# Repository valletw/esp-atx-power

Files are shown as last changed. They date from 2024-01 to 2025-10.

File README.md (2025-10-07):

# ESP32 ATX Power Controller

The purpose of this project is to control a computer remotely by connecting
directly to the ATX motherboard power IO control. The control will be done with
Home Assistant by using [ESPHome](https://esphome.io) firmware.

Custom software could be written by using ESP-IDF SDK but it is not the purpose
of this project.

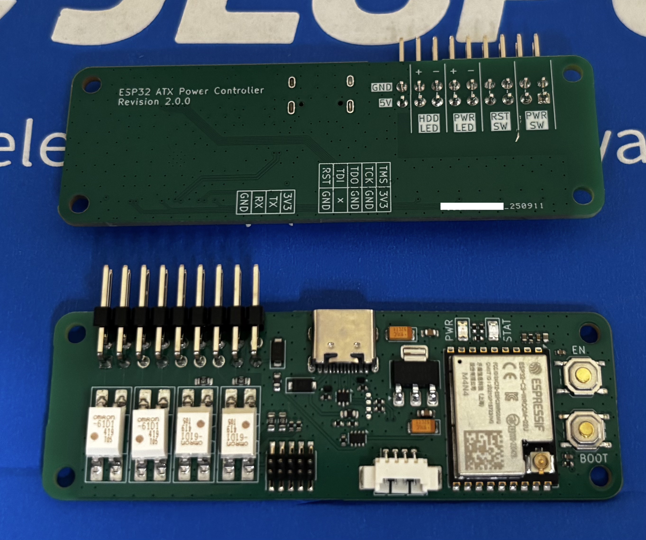
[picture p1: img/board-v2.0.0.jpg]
Board


## Hardware

Double 2.54mm pin headers are set for each ATX functionalities to manage:

- `PWR SW`: ATX power button
- `RST SW`: ATX reset button
- `PWR LED`: ATX power state LED
- `HDD LED`: ATX HDD activity LED

Two status LED are available:

- `PWR`: 3.3V state
- `STAT`: System status controlled by software

Two buttons are available for ESP32 boot sequence:

- `BOOT`: Control processor download mode on boot
- `EN`: Control processor reset

For advanced debug, the following connectors are available:

- 2x5 1.27mm pins header JTAG/SWD for external probe
- 4-pins Molex connector for UART

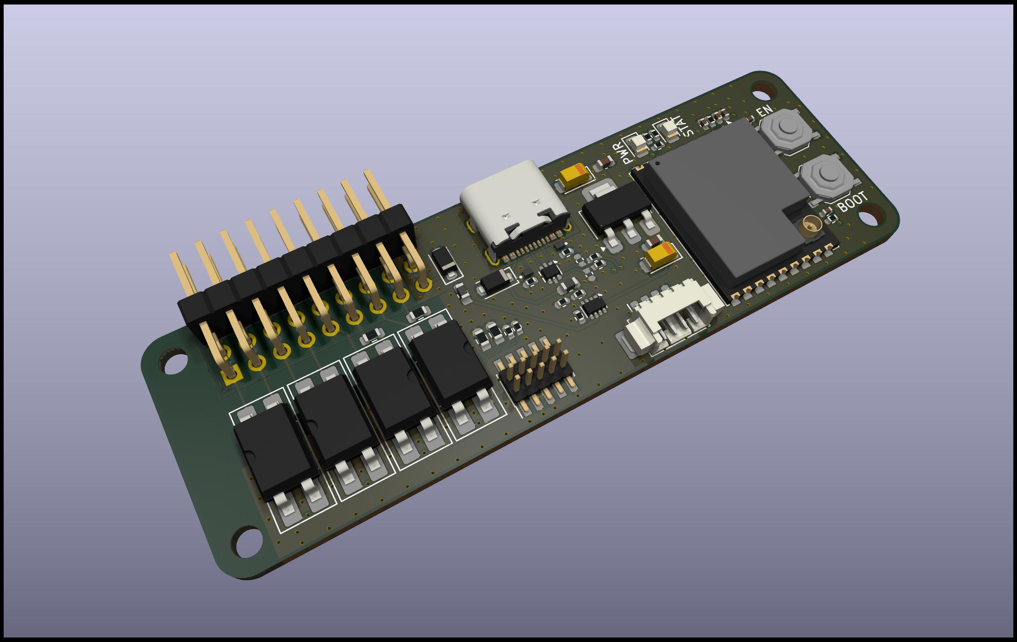
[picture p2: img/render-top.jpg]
Board top render

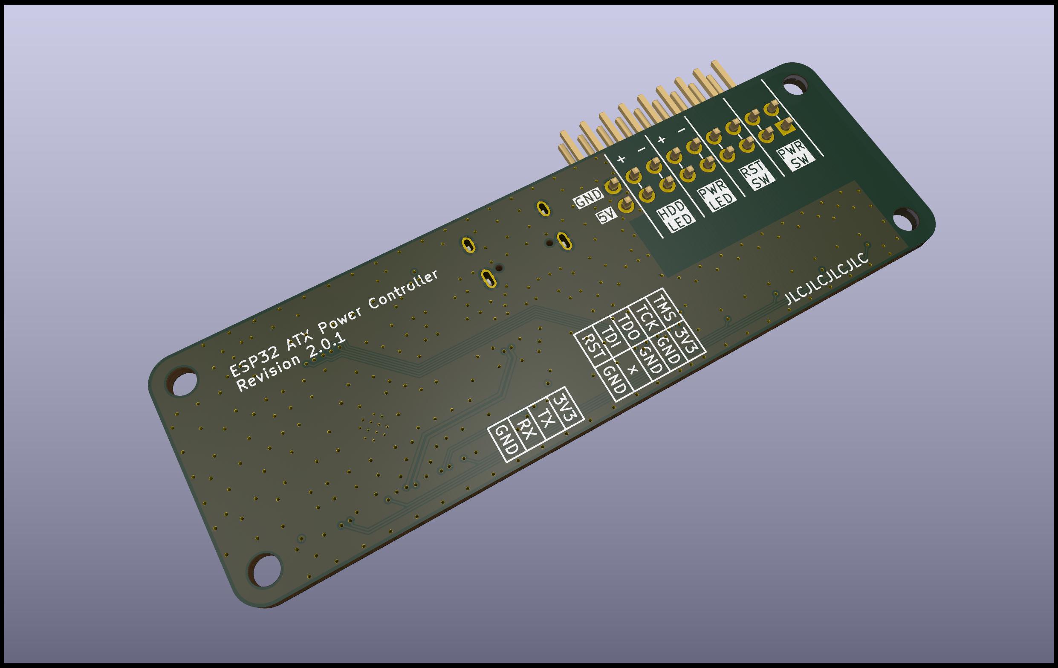
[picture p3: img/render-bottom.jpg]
Board bottom render


### Components choice

This project is based on an ESP32-C3 module to simplify design and ensure good
WiFi performance (with external antenna connector). ESP32 has been selected for
the big community to generate software and the frameworks available. Espressif
hardware design rules has been take into account following there
[documentation](https://docs.espressif.com/projects/esp-hardware-design-guidelines/en/latest/esp32c3/pcb-layout-design.html)

For easy debug and flashing, ESP32 with USB-CDC and JTAG support has been selected.
It allows to remove the USB-UART bridge of the previous design.

The optocouplers for electric isolation have been selected following the
[PiKVM](https://github.com/pikvm/pikvm) project experience. In the
[DIY PiKVM V2 instructions](https://docs.pikvm.org/v2/), the OMRON reference is
recommended. Others relays/optocouplers may not be sensitive enough or low-level
controlled.

The 3.3V to power all the components is generated from an LDO using the 5V of the
USB socket. It can also be powered from external 5V on pins header. Both external
5V and USB can be connected at the same time, a power MUX is used to switch between
both sources.

All others components has been selected from [JLCPCB](https://jlcpcb.com/parts/)
catalogue to minimize the cost and the assembly fees.

### Manufacturing

The board is manufactured by [JLCPCB](https://jlcpcb.com), here is the details
you will require to generate an order.

*Note: JLCPCB requests some modifications on output files, do not use direct
export from KiCad (check the FAQ)*

#### PCB

Files: [Gerbers](jlcpcb/gerbers.zip)

Configuration              | Value
---------------------------|---------------------------------
Base Materiel              | FR-4
Layers                     | 4
Dimensions                 | 76.56 x 25.10
Different design           | 1
Delivery format            | Single PCB
PCB thickness              | 1.6
PCB color                  | Green (other colors have fees)
Silkscreen                 | White
Materiel type              | FR4-Standard TG 135-140
Surface finish             | HASL
Specify layer sequence     | F_Cu / In1_Cu / In2_Cu / B_Cu
Impedance control          | Yes
Layer stackup              | JLC04161H-7628
Via covering               | Tented
Min via hole size/diameter | 0.3mm/0.45mm
Remove order number        | Specify a location

*Note: All options have not been detail here, keep default value.*

#### Assembly

Files: [BOM](jlcpcb/bom.csv), [CPL](jlcpcb/cpl.csv)

Configuration       | Value
--------------------|--------------------
PCBA type           | Economic
Assembly side       | Top
Tooling holes       | Added by JLCPCB

Verify "pick & place" orientations and positions on the web viewer

JLCPCB will add 2 tooling holes for assembly (1 mm diameter near the board corners).

*Note: All options have not been detail here, keep default value.*

### ESP32 Pinout

For those who want to reuse this project, here is the ESP32 pinout to manage the
different input/output.

Name              | Pin  | Direction
------------------|------|----------
System Status LED | IO8  | Output (strapping pin)
ATX Power Button  | IO0  | Output
ATX Reset Button  | IO1  | Output
ATX Power State   | IO3  | Input
ATX HDD Activity  | IO10 | Input

## ESPHome configuration

Device must be setup via USB connection the first time to flash the customized
firmware with sensors/buttons configuration.

Once it has been configured successfully, you should fix the device IP on your
router for easier Home Assistant configuration.

Note: Installation can be bypassed if already done or you can use docker image.
Check [ESPHome documentation](https://esphome.io/guides/getting_started_command_line.html)
for more details.

### Installation

```shell
pip install esphome
# Ensure your user session has the correct permission for serial port.
sudo usermod -a -G dialout <USERNAME>
```

### Customize

Depending of your installation and network, a `secrets.yaml` file must be
create with your specific configuration.

```yaml
# secrets.yaml
hostname: MyControllerHostname
wifi_ssid: MySSID
wifi_password: MyStrongPassphrase
wifi_fb_ssid: ATX Controller Fallback Hotspot
wifi_fb_password: StrongPassphrase
ota_password: MyOTAPassphrase
api_key: 32BytesBase64String
```

### Compile and flash

```shell
# Generate the firmware.
esphome compile esphome.yaml
# Flash the firmware to the ESP.
esphome run esphome.yaml
# Get logs.
esphome logs esphome.yaml
```

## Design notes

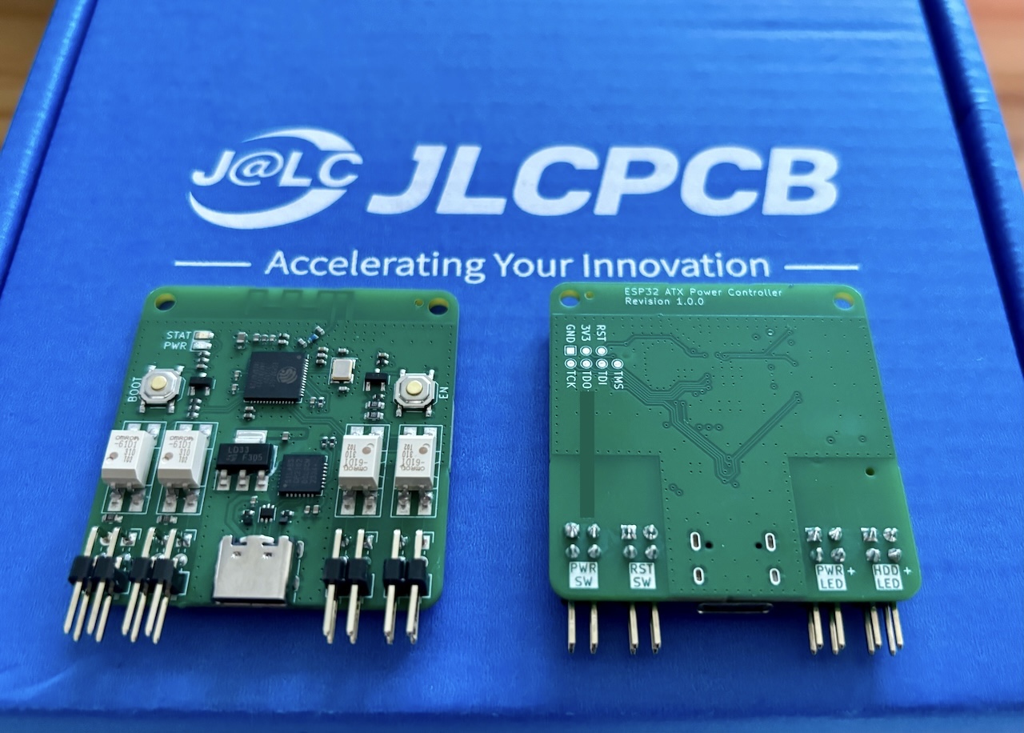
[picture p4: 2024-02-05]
img/board-v1.0.0.jpg

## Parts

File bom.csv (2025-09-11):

Reference | Value | Qty | Footprint | LCSC Part # | MFR Part # | Manufacturer | Datasheet
C101,C105,C106 | 100n | 3 | Capacitor_SMD:C_0402_1005Metric | C1525 | CL05B104KO5NNNC | Samsung Electro-Mechanics | https://datasheet.lcsc.com/lcsc/2304140030_Samsung-Electro-Mechanics-CL05B104KO5NNNC_C1525.pdf
D104 | Green | 1 | LED_SMD:LED_0805_2012Metric | C2297 | KT-0805G | Hubei KENTO Elec | https://jlcpcb.com/api/file/downloadByFileSystemAccessId/8639582106239348736
U102 | AMS1117-3.3 | 1 | Package_TO_SOT_SMD:SOT-223-3_TabPin2 | C6186 | AMS1117-3.3 | Advanced Monolithic Systems | http://www.advanced-monolithic.com/pdf/ds1117.pdf
C104,C111 | 10u | 2 | Capacitor_Tantalum_SMD:CP_EIA-3216-18_Kemet-A | C7171 | TAJA106K016RNJ
C103,C110 | 100n | 2 | Capacitor_SMD:C_0603_1608Metric | C14663 | CC0603KRX7R9BB104 | YAGEO | https://jlcpcb.com/api/file/downloadByFileSystemAccessId/8579707083955945472
L101,L102 | Ferrite Bead | 2 | Inductor_SMD:L_0603_1608Metric | C14709 | BLM18PG121SN1D | Murata Electronics | https://jlcpcb.com/api/file/downloadByFileSystemAccessId/8588900229559300096
C102 | 10u | 1 | Capacitor_SMD:C_0402_1005Metric | C15525 | CL05A106MQ5NUNC | Samsung Electro-Mechanics | https://datasheet.lcsc.com/lcsc/2208231630_Samsung-Electro-Mechanics-CL05A106MQ5NUNC_C15525.pdf
U103 | USBLC6-2P6 | 1 | Package_TO_SOT_SMD:SOT-666 | C15999 | USBLC6-2P6 | STMicroeletronics | https://www.st.com/resource/en/datasheet/usblc6-2.pdf
R116 | 0 | 1 | Resistor_SMD:R_0402_1005Metric | C17168 | 0402WGF0000TCE | UNI-ROYAL(Uniroyal Elec) | https://jlcpcb.com/api/file/downloadByFileSystemAccessId/8579705904671227904
R101,R102,R104,R106 | 390 | 4 | Resistor_SMD:R_0603_1608Metric | C23151 | 0603WAF3900T5E | UNI-ROYAL(Uniroyal Elec) | https://datasheet.lcsc.com/lcsc/2206010116_UNI-ROYAL-Uniroyal-Elec-0603WAF3900T5E_C23151.pdf
R112,R113 | 22 | 2 | Resistor_SMD:R_0402_1005Metric | C25092 | 0402WGF220JTCE | UNI-ROYAL(Uniroyal Elec) | https://jlcpcb.com/api/file/downloadByFileSystemAccessId/8579705904671227904
R114,R115 | 680 | 2 | Resistor_SMD:R_0402_1005Metric | C25130 | 0402WGF6800TCE | UNI-ROYAL(Uniroyal Elec) | https://jlcpcb.com/api/file/downloadByFileSystemAccessId/8579706055238078464
R103,R108,R109,R117,R118 | 10k | 5 | Resistor_SMD:R_0402_1005Metric | C25744 | 0402WGF1002TCE | UNI-ROYAL(Uniroyal Elec) | https://datasheet.lcsc.com/lcsc/2206010100_UNI-ROYAL-Uniroyal-Elec-0402WGF1002TCE_C25744.pdf
R105,R107 | 4.7k | 2 | Resistor_SMD:R_0402_1005Metric | C25900 | 0402WGF4701TCE | UNI-ROYAL(Uniroyal Elec) | https://datasheet.lcsc.com/lcsc/2206010045_UNI-ROYAL-Uniroyal-Elec-0402WGF4701TCE_C25900.pdf
R110,R111 | 5.1k | 2 | Resistor_SMD:R_0402_1005Metric | C25905 | 0402WGF5101TCE | UNI-ROYAL(Uniroyal Elec) | https://datasheet.lcsc.com/lcsc/2206010045_UNI-ROYAL-Uniroyal-Elec-0402WGF5101TCE_C25905.pdf
C107 | 1u | 1 | Capacitor_SMD:C_0402_1005Metric | C52923 | CL05A105KA5NQNC | Samsung Electro-Mechanics | https://datasheet.lcsc.com/lcsc/2304140030_Samsung-Electro-Mechanics-CL05A105KA5NQNC_C52923.pdf
D103 | Red | 1 | LED_SMD:LED_0805_2012Metric | C84256 | NCD0805R1 | Foshan NationStar Optoelectronics | https://jlcpcb.com/api/file/downloadByFileSystemAccessId/8550724080677908480
J103 | Conn_01x04 | 1 | Connector_Molex:Molex_PicoBlade_53261-0471_1x04-1MP_P1.25mm_Horizontal | C240847 | 532610471 | MOLEX | https://www.molex.com/content/dam/molex/molex-dot-com/products/automated/en-us/salesdrawingpdf/532/53261/532610471_sd.pdf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
SW101,SW102 | TS-1187A-B-A-B | 2 | Button_Switch_SMD:SW_Push_1P1T_XKB_TS-1187A | C318884 | TS-1187A-B-A-B | XKB Connectivity | https://datasheet.lcsc.com/lcsc/2304140030_XKB-Connectivity-TS-1187A-B-A-B_C318884.pdf
D101,D102 | TPD1E05U06 | 2 | Package_SON:Texas_DPY0002A_0.6x1mm_P0.65mm | C436349 | TPD1E05U06DPYR | Texas Instruments | https://www.ti.com/lit/ds/symlink/tpd4e05u06.pdf
K101,K102,K103,K104 | G3VM-61D1 | 4 | Package_DIP:DIP-4_W8.89mm_SMDSocket_LongPads | C469131 | G3VM-61D1(TR) | Omron Electronics | https://www.omron.com/ecb/products/pdf/en-g3vm_61a1_d1.pdf
J102 | Conn_02x09_Odd_Even | 1 | Connector_PinHeader_2.54mm:PinHeader_2x09_P2.54mm_Horizontal | C2894989 | PZ254-2-09-W-8.5 | HCTL | https://jlcpcb.com/api/file/downloadByFileSystemAccessId/8588944235408338944
U101 | ESP32-C3-WROOM-02U | 1 | RF_Module:ESP32-C3-WROOM-02U | C2926676 | ESP32-C3-WROOM-02U-N4 | Espressif Systems | https://www.espressif.com/sites/default/files/documentation/esp32-c3-wroom-02_datasheet_en.pdf
J105 | GT-USB-7010ASV | 1 | Connector_USB:USB_C_Receptacle_G-Switch_GT-USB-7010ASV | C2988369 | GT-USB-7010ASV | G-Switch | https://datasheet.lcsc.com/lcsc/2303271630_G-Switch-GT-USB-7010ASV_C2988369.pdf
U104 | TPS2116DRL | 1 | Package_TO_SOT_SMD:SOT-583-8 | C3235557 | TPS2116DRLR | Texas Instruments | https://www.ti.com/lit/ds/symlink/tps2116.pdf
D105,D106 | SMF5.0A | 2 | Diode_SMD:D_SOD-123F | C19077497 | SMF5.0A | hongjiacheng | https://jlcpcb.com/api/file/downloadByFileSystemAccessId/8564880887079854080
J101 | Conn_ARM_JTAG_SWD_10 | 1 | Connector_PinHeader_1.27mm:PinHeader_2x05_P1.27mm_Vertical_SMD | C41376037 | HX PZ1.27-2x5P TP | hanxia | http://infocenter.arm.com/help/topic/com.arm.doc.ddi0314h/DDI0314H_coresight_components_trm.pdf

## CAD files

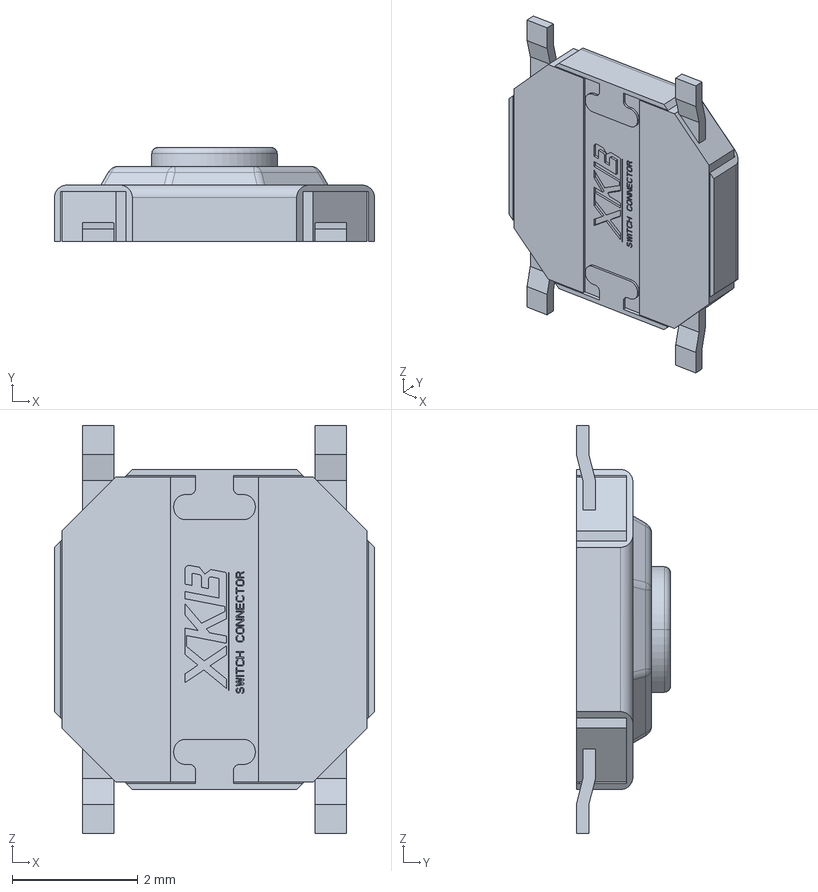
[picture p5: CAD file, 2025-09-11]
librairies/3dmodels/TS-1187A-B-A-B.stp
5.10 x 1.50 x 6.50 mm

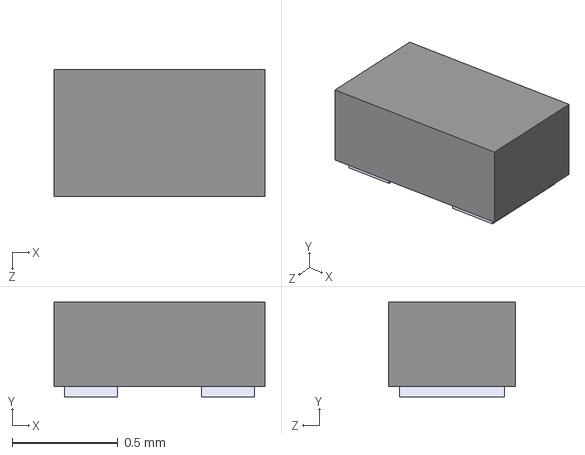
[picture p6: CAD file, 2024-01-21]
librairies/3dmodels/TPD1E05U06DPYR.step
1.00 x 0.45 x 0.6 mm

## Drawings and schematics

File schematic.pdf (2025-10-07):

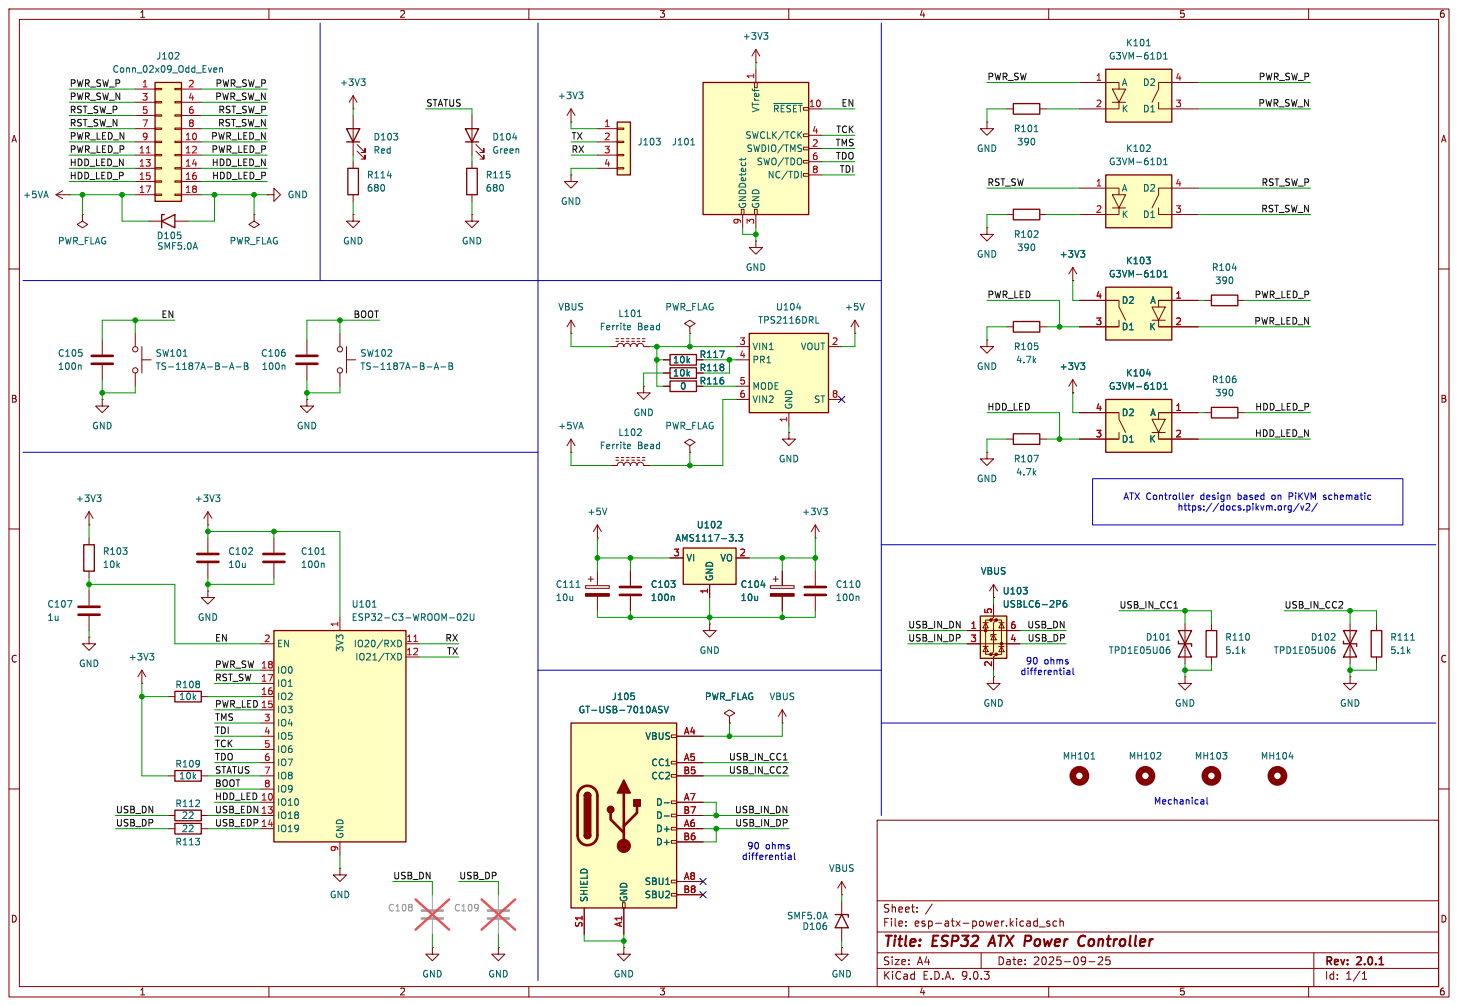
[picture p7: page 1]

3 ~{RESET}10 SWCLK/TCK 4 SWDIO/TMS 2 SWO/TDO 6 NC/TDI 8

Id: 1/1 Title: ESP32 ATX Power Controller File: esp-atx-power.kicad_sch Sheet: / R103

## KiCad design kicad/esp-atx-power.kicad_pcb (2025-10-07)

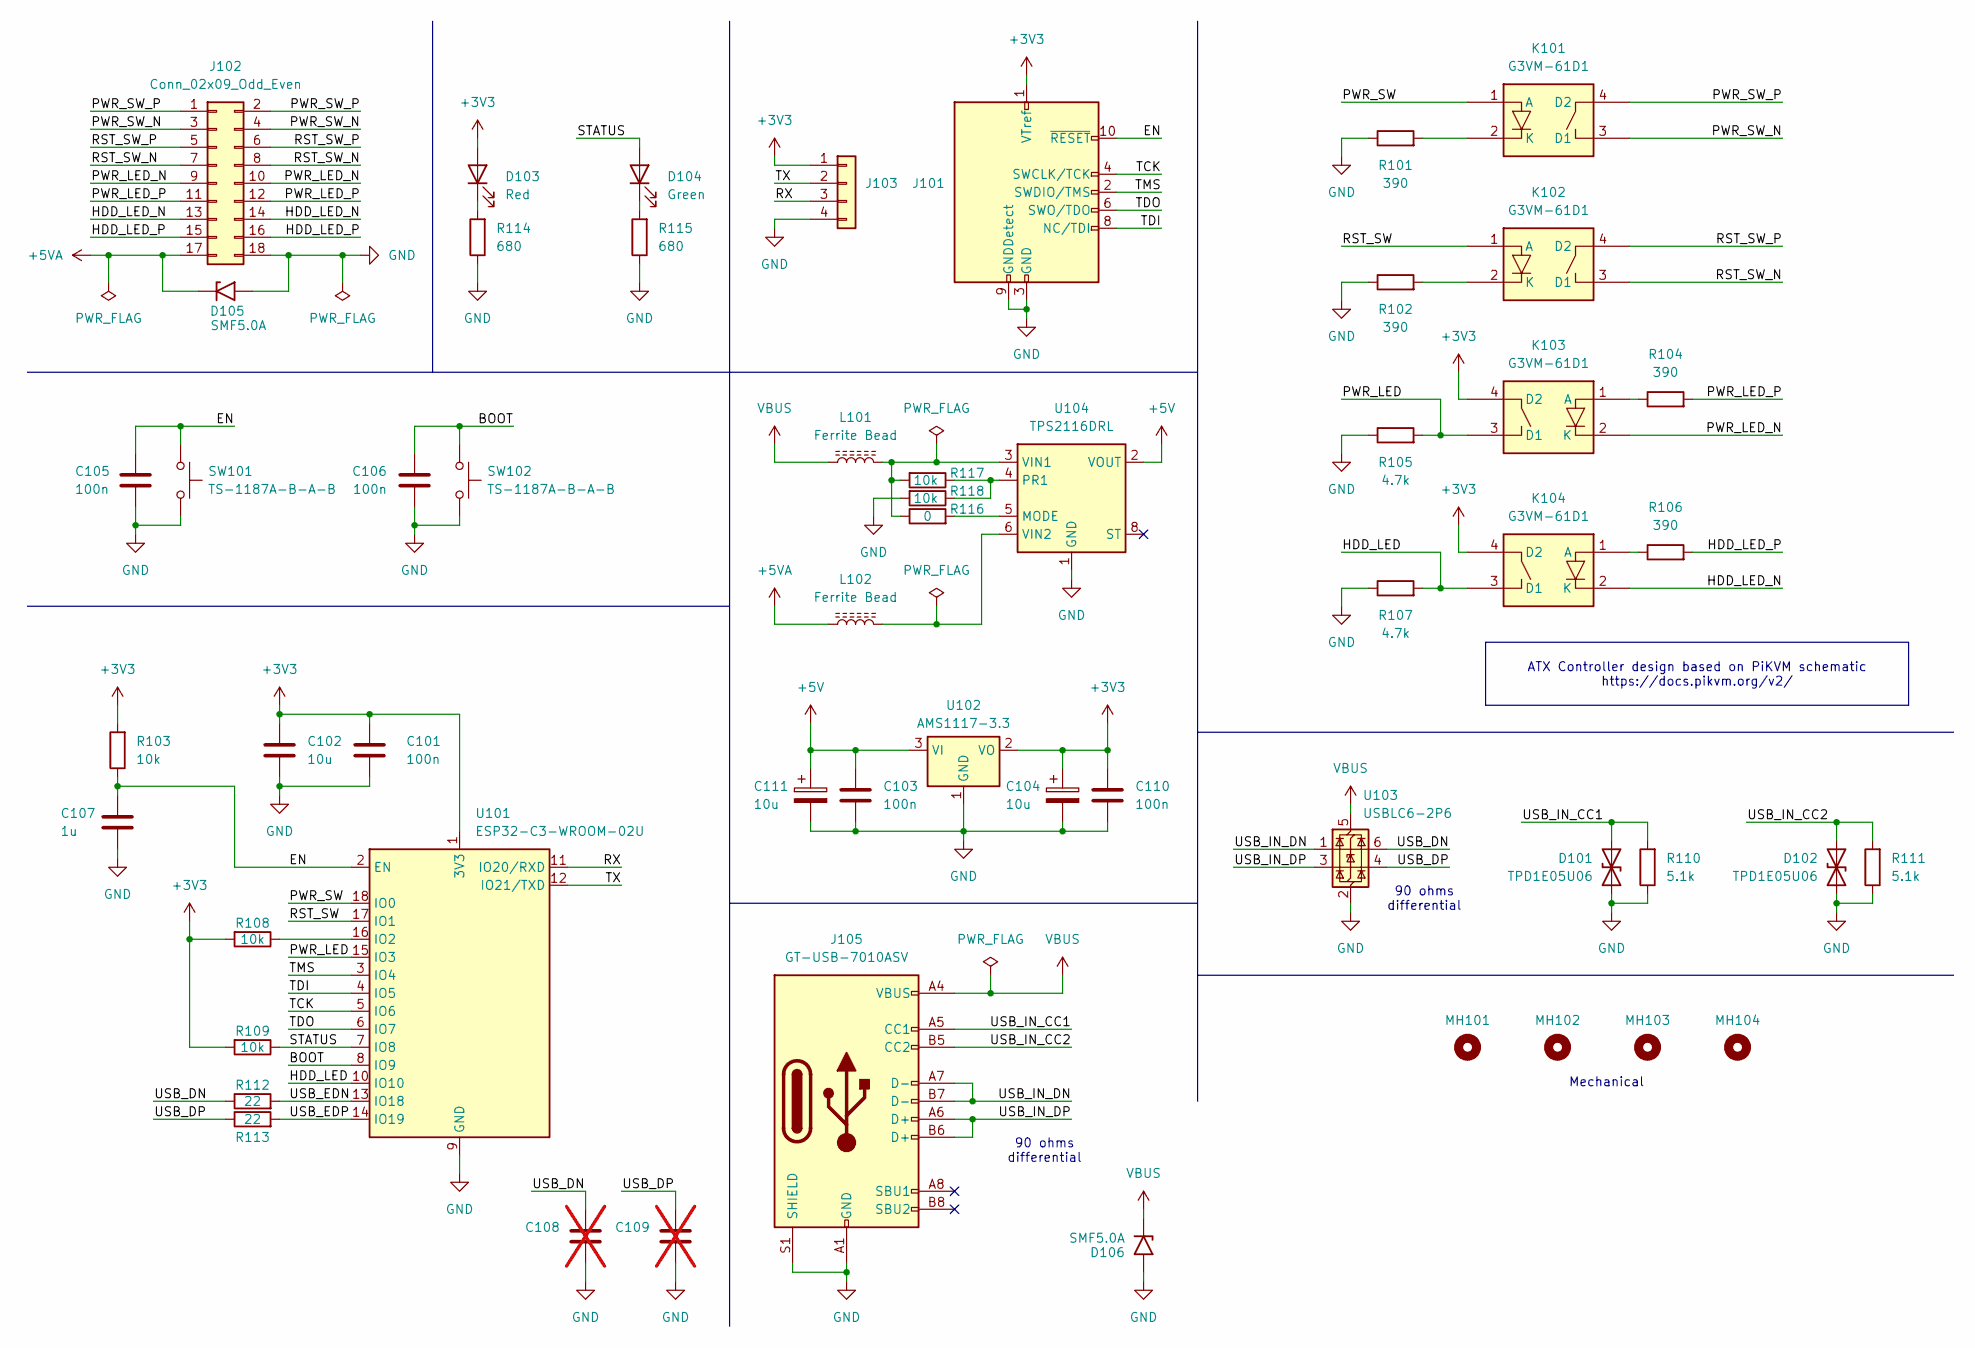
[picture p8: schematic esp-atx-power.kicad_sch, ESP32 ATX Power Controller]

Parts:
C101, C105, C106: 100n; C_0402_1005Metric; MFR Part # CL05B104KO5NNNC; LCSC Part # C1525
C102: 10u; C_0402_1005Metric; MFR Part # CL05A106MQ5NUNC; LCSC Part # C15525
C103, C110: 100n; C_0603_1608Metric; MFR Part # CC0603KRX7R9BB104; LCSC Part # C14663
C104, C111: 10u; CP_EIA-3216-18_Kemet-A; MFR Part # TAJA106K016RNJ; LCSC Part # C7171
C107: 1u; C_0402_1005Metric; MFR Part # CL05A105KA5NQNC; LCSC Part # C52923
C108, C109: C_0402_1005Metric; not fitted
D101, D102: TPD1E05U06; Texas_DPY0002A_0.6x1mm_P0.65mm; MFR Part # TPD1E05U06DPYR; LCSC Part # C436349
D103: Red; LED_0805_2012Metric; MFR Part # NCD0805R1; LCSC Part # C84256
D104: Green; LED_0805_2012Metric; MFR Part # KT-0805G; LCSC Part # C2297
D105, D106: SMF5.0A; D_SOD-123F; MFR Part # SMF5.0A; LCSC Part # C19077497
J101: Conn_ARM_JTAG_SWD_10; PinHeader_2x05_P1.27mm_Vertical_SMD; MFR Part # HX PZ1.27-2x5P TP; LCSC Part # C41376037
J102: Conn_02x09_Odd_Even; PinHeader_2x09_P2.54mm_Horizontal; MFR Part # PZ254-2-09-W-8.5; LCSC Part # C2894989
J103: Conn_01x04; Molex_PicoBlade_53261-0471_1x04-1MP_P1.25mm_Horizontal; MFR Part # 532610471; LCSC Part # C240847
J105: GT-USB-7010ASV; USB_C_Receptacle_G-Switch_GT-USB-7010ASV; MFR Part # GT-USB-7010ASV; LCSC Part # C2988369
K101, K102, K103, K104: G3VM-61D1; DIP-4_W8.89mm_SMDSocket_LongPads; MFR Part # G3VM-61D1(TR); LCSC Part # C469131
L101, L102: Ferrite Bead; L_0603_1608Metric; MFR Part # BLM18PG121SN1D; LCSC Part # C14709
MH101, MH102, MH103, MH104: MountingHole_2.7mm_M2.5_ISO7380
R101, R102, R104, R106: 390; R_0603_1608Metric; MFR Part # 0603WAF3900T5E; LCSC Part # C23151
R103, R108, R109, R117, R118: 10k; R_0402_1005Metric; MFR Part # 0402WGF1002TCE; LCSC Part # C25744
R105, R107: 4.7k; R_0402_1005Metric; MFR Part # 0402WGF4701TCE; LCSC Part # C25900
R110, R111: 5.1k; R_0402_1005Metric; MFR Part # 0402WGF5101TCE; LCSC Part # C25905
R112, R113: 22; R_0402_1005Metric; MFR Part # 0402WGF220JTCE; LCSC Part # C25092
R114, R115: 680; R_0402_1005Metric; MFR Part # 0402WGF6800TCE; LCSC Part # C25130
R116: 0; R_0402_1005Metric; MFR Part # 0402WGF0000TCE; LCSC Part # C17168
SW101, SW102: TS-1187A-B-A-B; SW_Push_1P1T_XKB_TS-1187A; MFR Part # TS-1187A-B-A-B; LCSC Part # C318884
U101: ESP32-C3-WROOM-02U; MFR Part # ESP32-C3-WROOM-02U-N4; LCSC Part # C2926676
U102: AMS1117-3.3; SOT-223-3_TabPin2; MFR Part # AMS1117-3.3; LCSC Part # C6186
U103: USBLC6-2P6; SOT-666; MFR Part # USBLC6-2P6; LCSC Part # C15999
U104: TPS2116DRL; SOT-583-8; MFR Part # TPS2116DRLR; LCSC Part # C3235557

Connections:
+3V3: C101.2, C102.1, C104.1, C110.1, D103.2 (A), J101.1 (VTref), J103.1, K103.4 (D2), K104.4 (D2), R103.2, R108.2, R109.2, U101.1 (3V3), U102.2 (VO)
+5V: C103.1, C111.1, U102.3 (VI), U104.2 (VOUT), U104.7 (VOUT)
+5VA: D105.1 (A1), J102.17, L102.1
/BOOT: C106.1, SW102.1, U101.8 (IO9)
/EN: C105.1, C107.1, J101.10 (~RESET), R103.1, SW101.1, U101.2 (EN)
/HDD_LED: K104.3 (D1), R107.2, U101.10 (IO10)
/HDD_LED_N: J102.13, J102.14, K104.2 (K)
/HDD_LED_P: J102.15, J102.16, R106.2
/PWR_LED: K103.3 (D1), R105.2, U101.15 (IO3)
/PWR_LED_N: J102.9, J102.10, K103.2 (K)
/PWR_LED_P: J102.11, J102.12, R104.2
/PWR_SW: K101.1 (A), U101.18 (IO0)
/PWR_SW_N: J102.3, J102.4, K101.3 (D1)
/PWR_SW_P: J102.1, J102.2, K101.4 (D2)
/RST_SW: K102.1 (A), U101.17 (IO1)
/RST_SW_N: J102.7, J102.8, K102.3 (D1)
/RST_SW_P: J102.5, J102.6, K102.4 (D2)
/RX: J103.3, U101.11 (IO20/RXD)
/STATUS: D104.2 (A), R109.1, U101.7 (IO8)
/TCK: J101.4 (SWCLK/TCK), U101.5 (IO6)
/TDI: J101.8 (NC/TDI), U101.4 (IO5)
/TDO: J101.6 (SWO/TDO), U101.6 (IO7)
/TMS: J101.2 (SWDIO/TMS), U101.3 (IO4)
/TX: J103.2, U101.12 (IO21/TXD)
/USB_DN: C108.1, R112.1, U103.6 (I/O1)
/USB_DP: C109.1, R113.1, U103.4 (I/O2)
/USB_EDN: R112.2, U101.13 (IO18)
/USB_EDP: R113.2, U101.14 (IO19)
/USB_IN_CC1: D101.2 (A2), J105.A5 (CC1), R110.2
/USB_IN_CC2: D102.2 (A2), J105.B5 (CC2), R111.2
/USB_IN_DN: J105.A7 (D-), J105.B7 (D-), U103.1 (I/O1)
/USB_IN_DP: J105.A6 (D+), J105.B6 (D+), U103.3 (I/O2)
GND: C101.1, C102.2, C103.2, C104.2, C105.2, C106.2, C107.2, C108.2, C109.2, C110.2, C111.2, D101.1 (A1), D102.1 (A1), D105.2 (A2), D106.2 (A2), J101.3 (GND), J101.5 (GND), J101.9 (GNDDetect), J102.18, J103.4, J105.A1 (GND), J105.A12 (GND), J105.B1 (GND), J105.B12 (GND), J105.S1 (SHIELD), R101.1, R102.1, R105.1, R107.1, R110.1, R111.1, R114.1, R115.1, R118.2, SW101.2, SW102.2, U101.9 (GND), U101.19 (GND), U102.1 (GND), U103.2 (GND), U104.1 (GND)
unnamed: D103.1 (K), R114.2
unnamed: D104.1 (K), R115.2
unnamed: K101.2 (K), R101.2
unnamed: K102.2 (K), R102.2
unnamed: K103.1 (A), R104.1
unnamed: K104.1 (A), R106.1
unnamed: R108.1, U101.16 (IO2)
unnamed: R116.2, U104.5 (MODE)
unnamed: R117.1, R118.1, U104.4 (PR1)
unnamed: L101.2, R116.1, R117.2, U104.3 (VIN1)
unnamed: L102.2, U104.6 (VIN2)
VBUS: D106.1 (A1), J105.A4 (VBUS), J105.A9 (VBUS), J105.B4 (VBUS), J105.B9 (VBUS), L101.1, U103.5 (VBUS)

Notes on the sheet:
90 ohms differential
Mechanical
ATX Controller design based on PiKVM schematic https://docs.pikvm.org/v2/

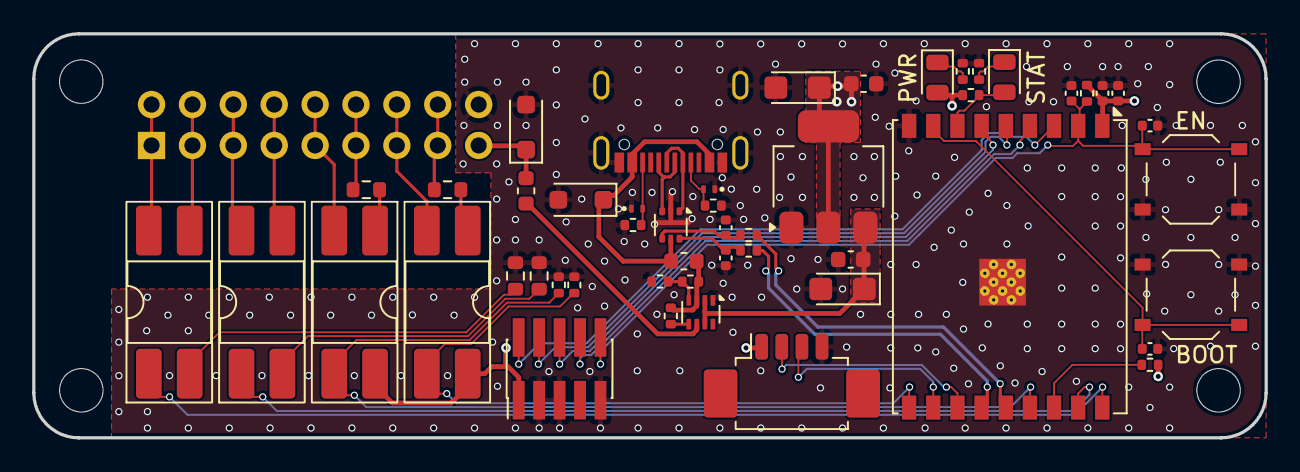
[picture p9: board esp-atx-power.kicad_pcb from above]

Board: 4 copper layers, 76.6 x 25.1 mm, 55 parts (0 on the bottom side), 45 nets.

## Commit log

2024-01-21 Add KiCad project files and custom component libraroes
    [TPD1E05U06DPYR.step, esp-atx-power.kicad_pcb, esp-atx-power.kicad_sch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]
2024-02-05 Provide KiCad output files
    - Schematic
    - BOM
    - Gerber
    - Render
    [bom.csv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]
2024-02-05 Fix RTS/DTR and increase LEDs resistors
    - RTS/DTR has been inverted and RTS assertin doesn't reset the board.
    - Increase the LED resistors to decrease brightness
    - Change JLCPCB order number position
    [bom.csv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]
2025-08-29 Update WiFi TX power with fast connection
    Mitigate "auth expired" issue
2025-08-29 Add WiFi RSSI sensor
2025-09-11 Update board form factor and change ESP module
    - PCB antenna is not well working inside computer casing
    - Select an ESP with external antenna connector
    - Remove USB-UART bridge which is no longer required for flashing
    - Use on unique pin header instead of 4
    - Add 5V external power supply in case USB port is not available
    [TS-1187A-B-A-B.stp, esp-atx-power.kicad_pcb, esp-atx-power.kicad_sch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]
2025-09-11 Generate new KiCad output files
    [bom.csv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]
2025-10-07 Fix TVS diode orientation
    The selected diode was not bidirectional, update schematic symbol
    to take it into account and fix orientation on VBUS (short circuit).
    [cpl.csv, esp-atx-power-B_Cu.gbl, esp-atx-power-B_Fab.gbr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]

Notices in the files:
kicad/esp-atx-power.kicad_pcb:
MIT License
